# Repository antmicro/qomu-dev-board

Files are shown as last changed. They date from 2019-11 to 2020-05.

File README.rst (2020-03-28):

======================
Qomu Development Board
======================

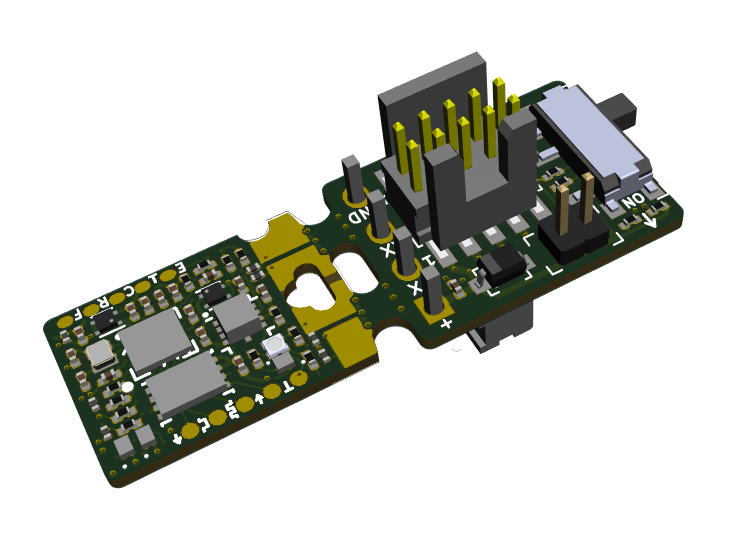
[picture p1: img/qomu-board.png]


Overview
========

This repository contains open hardware design files for the Qomu development board based on the QuickLogic `EOS S3 Sensor Processing Platform <https://www.quicklogic.com/products/eos-s3/>`_.
The design files were created by `Antmicro <https://www.antmicro.com>`_ in cooperation with `QuickLogic <https://www.quicklogic.com/>`_.
The board is small enough to fit into a USB socket.
This allows the user to explore functionalities of the EOS S3 platform on the go without cables or taking up space on your desk.
The board has an additional break-away part with debug connectors that speeds up initial bringup and software development.

Key features
============

* EOS S3 Sensor Processing Platform
* 16Mbit of external flash memory
* Accelerometer
* User RGB LED
* Capacitive touch pads
* Powered with 5.0VDC from USB port
* USB data signals tied to programmable logic

Layout and dimensions
=====================

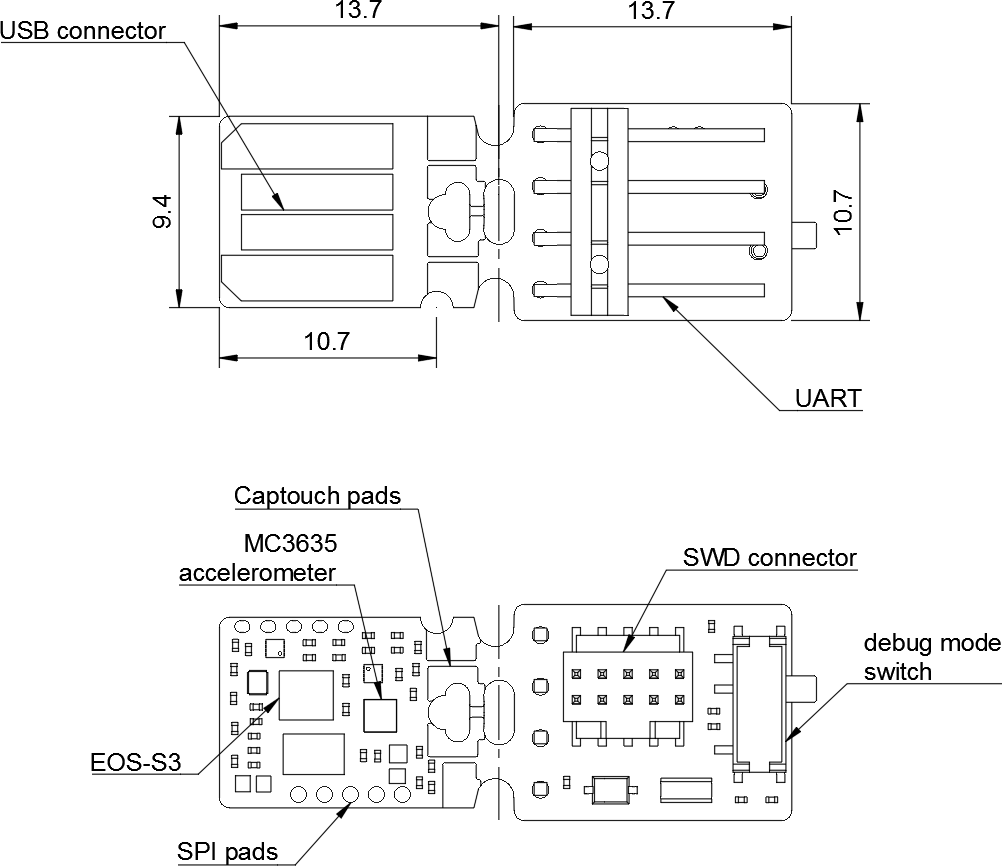
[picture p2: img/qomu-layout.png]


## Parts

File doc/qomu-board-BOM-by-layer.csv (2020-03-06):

Reference | Quantity | Value | Footprint | Manufacturer | MPN | Layer
J2 | 1 | 825437-4 | TE_825437-4 | TE Connectivity | 825437-4 | Top
C1 C15 C16 C2 C7 C9 | 6 | C_2u2_0201 | C_0201_0603Metric | Samsung | CL03A225MP3CRNC | Bottom
C10 C12 C3 C4 C5 C6 C8 | 7 | C_100n_0201 | C_0201_0603Metric | Murata | GRM033R60J104KE19D | Bottom
C13 C14 | 2 | C_8p_0201 | C_0201_0603Metric | Murata | GRM0335C1E8R0DA01D | Bottom
D1 D2 D3 D4 D5 D6 D7 | 7 | D_Small-Device | X1-DFN1006-2 | Diodes Inc. | D5V0L1B2LP3-7 | Bottom
D8 | 1 | SD05C.TCT | SOD-323-SD05 | Semtec | SD05C.TCT | Bottom
IC1 | 1 | EOS-S3 | 42-WLCSP | Quicklogic | EOS-S3-42-WLCSP | Bottom
J1 | 1 | FTSH-105-01-L-DV-K | PinHeader_2x5_P1.27_SMD | Samtec Inc. | FTSH-105-01-L-DV-K | Bottom
J3 | 1 | MC-HVT1-S02-G | PinHeader_1x2_P1.27mm_Drill.7mm_with_622002115121_plug | Multicomp | MC-HVT1-S02-G | Bottom
Q1 Q2 Q3 | 3 | RV1C002UN | VML0806 | ROHM Semiconductor | RV1C002UN | Bottom
R1 R13 R15 R2 R3 R4 R5 R6 | 8 | R_10k_0201 | R_0201_0603Metric | Panasonic | ERJ1GNF1002C | Bottom
R10 R7 | 2 | R_0R_0201 | R_0201_0603Metric | Multicomp | MCRE000086 | Bottom
R11 R12 | 2 | R_22R_0201 | R_0201_0603Metric | Multicomp | MCRE000100 | Bottom
R16 R17 | 2 | R_100R_0201 | R_0201_0603Metric | Multicomp | MCRE000116 | Bottom
R18 | 1 | R_220R_0201 | R_0201_0603Metric | Multicomp | MCRE000124 | Bottom
R8 | 1 | R_4k7_0201 | R_0201_0603Metric | Vishay | CRCW02014K70FNED | Bottom
R9 | 1 | R_1k5_0201 | R_0201_0603Metric | Multicomp | MCRE000144 | Bottom
S1 | 1 | MSS3-V-T_R | Switch_Slide_MSS3 | Diptronics | MSS3-V-T/R | Bottom
U1 U2 | 2 | LDO-X2SON | Texas_X2SON-4_1x1mm_P0.65mm | Microchip | MIC5504-3.3YMT | Bottom
U10 | 1 | RGB-LED | LED-RGB-5DS-UHD1110-FKA | Cree | UHD1110-FKA | Bottom
U4 | 1 | GD25Q16CEIGR | GD25Q16CEIGR | GigaDevice Semiconductor | GD25Q16CEIGR | Bottom
U5 | 1 | MC3635 | MC3635 | mCube | MC3635 | Bottom
XTAL1 | 1 | ECS-_327-12_5-1210-TR | XTAL_ECS-.327-12.5-1210-TR | ECS Inc. | ECS-.327-12.5-1210-TR | Bottom
N1 | 1 | oshw_logo | OSHW-Logo2_7.3x6mm_Copper_Mask |  |  | Virtual
N2 | 1 | antmicro_logo | antmicro-logo_midlayer_4mm |  |  | Virtual
N3 | 1 | ql_logo | Ql_logo_mid_9mm |  |  | Virtual
SW2 | 1 | PADS |  | N/A | N/A | Virtual
TP1 TP10 TP2 TP3 TP4 TP5 TP6 TP7 TP8 TP9 | 10 | TP_SMD_0_75MM | Testpoint_smd_0_75mm |  |  | Virtual
U9 | 1 | USB-B |  | N/A | N/A | Virtual

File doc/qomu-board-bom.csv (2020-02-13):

Reference | Quantity | Value | Footprint | Manufacturer | MPN
C1 C2 C7 C9 | 4 | C_2u2_0201 | C_0201_0603Metric | Samsung | CL03A225MP3CRNC
C10 C11 C12 C3 C4 C5 C6 C8 | 8 | C_100n_0201 | C_0201_0603Metric | Murata | GRM033R60J104KE19D
C13 C14 | 2 | C_8p_0201 | C_0201_0603Metric | Murata | GRM0335C1E8R0DA01D
D1 D2 D3 D4 D5 D6 D7 | 7 | D_Small-Device | X1-DFN1006-2 | Diodes Inc. | D5V0L1B2LP3-7
D8 | 1 | SD05C.TCT | SOD-323-SD05 | Semtec | SD05C.TCT
IC1 | 1 | EOS-S3 | 42-WLCSP | Quicklogic | EOS-S3-42-WLCSP
J1 | 1 | FTSH-105-01-L-DV-K | PinHeader_2x5_P1.27_SMD | Samtec Inc. | FTSH-105-01-L-DV-K
J2 | 1 | 825437-4 | TE_825437-4 | TE Connectivity | 825437-4
J3 | 1 | MC-HVT1-S02-G | PinHeader_1x2_P1.27mm_Drill.7mm_with_622002115121_plug | Multicomp | MC-HVT1-S02-G
N1 | 1 | oshw_logo | OSHW-Logo2_7.3x6mm_Copper_Mask
N2 | 1 | antmicro_logo | antmicro-logo_midlayer_4mm
N3 | 1 | ql_logo | Ql_logo_mid_9mm
Q1 Q2 Q3 | 3 | RV1C002UN | VML0806 | ROHM Semiconductor | RV1C002UN
R1 R13 R15 R2 R3 R4 R5 R6 | 8 | R_10k_0201 | R_0201_0603Metric | Panasonic | ERJ1GNF1002C
R10 R7 | 2 | R_0R_0201 | R_0201_0603Metric | Multicomp | MCRE000086
R11 R12 | 2 | R_22R_0201 | R_0201_0603Metric | MCRE000100
R16 R17 | 2 | R_100R_0201 | R_0201_0603Metric | Multicomp | MCRE000116
R18 | 1 | R_220R_0201 | R_0201_0603Metric | Multicomp | MCRE000124
R8 | 1 | R_4k7_0201 | R_0201_0603Metric | Vishay | CRCW02014K70FNED
R9 | 1 | R_1k5_0201 | R_0201_0603Metric | Multicomp | MCRE000144
S1 | 1 | MSS3-V-T_R | Switch_Slide_MSS3 | Diptronics | MSS3-V-T/R
SW2 | 1 | PADS |  | N/A | N/A
TP1 TP10 TP2 TP3 TP4 TP5 TP6 TP7 TP8 TP9 | 10 | TP_SMD_0_75MM | Testpoint_smd_0_75mm
U1 U2 | 2 | LDO-X2SON | Texas_X2SON-4_1x1mm_P0.65mm | Microchip | MIC5504-3.3YMT
U10 | 1 | RGB-LED | LED-RGB-5DS-UHD1110-FKA | Cree | UHD1110-FKA
U4 | 1 | GD25Q16CEIGR | GD25Q16CEIGR | GigaDevice Semiconductor | GD25Q16CEIGR
U5 | 1 | MC3635 | MC3635 | mCube | MC3635
U9 | 1 | USB-B |  | N/A | N/A
XTAL1 | 1 | ECS-_327-12_5-1210-TR | XTAL_ECS-.327-12.5-1210-TR | ECS Inc. | ECS-.327-12.5-1210-TR

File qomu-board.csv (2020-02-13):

Reference | Value | Footprint | Datasheet | MPN | Manufacturer | Field4 | Field5 | Field6 | Field7 | Field8
U9 | USB-B | qomu-board:USB-PCB |  | N/A | N/A
U10 | UHD1110-FKA | qomu-board-footprints:LED-RGB-5DS-UHD1110-FKA | https://www.cree.com/led-components/media/documents/ds-UHD1110-FKA.pdf | UHD1110-FKA | Cree
R12 | 22R | qomu-board-footprints:R_0201_0603Metric | Multicomp | ANY | MCRE000100
R9 | 1k5 | qomu-board-footprints:R_0201_0603Metric |  | MCRE000144 | Multicomp
SW2 | Captouch Pads | qomu-board:captouch-edge |  | N/A | N/A
D1 | D5V0L1B2LP3-7 | qomu-board-footprints:X1-DFN1006-2 | https://www.diodes.com/assets/Datasheets/D5V0L1B2LP3.pdf | D5V0L1B2LP3-7 | Diodes Inc.
D2 | D5V0L1B2LP3-7 | qomu-board-footprints:X1-DFN1006-2 | https://www.diodes.com/assets/Datasheets/D5V0L1B2LP3.pdf | D5V0L1B2LP3-7 | Diodes Inc.
D3 | D5V0L1B2LP3-7 | qomu-board-footprints:X1-DFN1006-2 | https://www.diodes.com/assets/Datasheets/D5V0L1B2LP3.pdf | D5V0L1B2LP3-7 | Diodes Inc.
D4 | D5V0L1B2LP3-7 | qomu-board-footprints:X1-DFN1006-2 | https://www.diodes.com/assets/Datasheets/D5V0L1B2LP3.pdf | D5V0L1B2LP3-7 | Diodes Inc.
D6 | D5V0L1B2LP3-7 | qomu-board-footprints:X1-DFN1006-2 | https://www.diodes.com/assets/Datasheets/D5V0L1B2LP3.pdf | D5V0L1B2LP3-7 | Diodes Inc.
D7 | D5V0L1B2LP3-7 | qomu-board-footprints:X1-DFN1006-2 | https://www.diodes.com/assets/Datasheets/D5V0L1B2LP3.pdf | D5V0L1B2LP3-7 | Diodes Inc.
D5 | VCUT05E1-SD0 | qomu-board-footprints:X1-DFN1006-2 | http://www.vishay.com/docs/85900/vcut05e1-sd0.pdf | D5V0L1B2LP3-7 | Diodes Inc.
R1 | 10k | qomu-board-footprints:R_0201_0603Metric |  | ERJ1GNF1002C | Panasonic
R11 | 22R | qomu-board-footprints:R_0201_0603Metric | Multicomp | ANY | MCRE000100
C2 | 2u2/10V | qomu-board-footprints:C_0201_0603Metric |  | CL03A225MP3CRNC | Samsung
C9 | 2u2/10V | qomu-board-footprints:C_0201_0603Metric |  | CL03A225MP3CRNC | Samsung
U4 | GD25Q16CEIGR | qomu-board:GD25Q16CEIGR | http://www.gigadevice.com/datasheet/gd25q16c/ | GD25Q16CEIGR | GigaDevice Semiconductor
R3 | 4k7 | qomu-board-footprints:R_0201_0603Metric |  | ERJ1GNF1002C | Panasonic
R4 | 4k7 | qomu-board-footprints:R_0201_0603Metric |  | ERJ1GNF1002C | Panasonic
C5 | 100n | qomu-board-footprints:C_0201_0603Metric |  | GRM033R60J104KE19D | Murata
U5 | MC3635 | qomu-board:MC3635 | https://mcubemems.com/wp-content/uploads/2019/06/MC3635-Datasheet-APS-048-0044v1.6.pdf | MC3635 | mCube
C4 | 100n | qomu-board-footprints:C_0201_0603Metric |  | GRM033R60J104KE19D | Murata
U2 | MIC5504-3.3YMT | qomu-board-footprints:Texas_X2SON-4_1x1mm_P0.65mm |  | MIC5504-3.3YMT | Microchip
C3 | 100n | qomu-board-footprints:C_0201_0603Metric |  | GRM033R60J104KE19D | Murata
C6 | 100n | qomu-board-footprints:C_0201_0603Metric |  | GRM033R60J104KE19D | Murata
C8 | 100n | qomu-board-footprints:C_0201_0603Metric |  | GRM033R60J104KE19D | Murata
C10 | 100n | qomu-board-footprints:C_0201_0603Metric |  | GRM033R60J104KE19D | Murata
C11 | 100n | qomu-board-footprints:C_0201_0603Metric |  | GRM033R60J104KE19D | Murata
U1 | MIC5504-3.3YMT | qomu-board-footprints:Texas_X2SON-4_1x1mm_P0.65mm |  | MIC5504-3.3YMT | Microchip
C7 | 2u2/10V | qomu-board-footprints:C_0201_0603Metric |  | CL03A225MP3CRNC | Samsung
C1 | 2u2/10V | qomu-board-footprints:C_0201_0603Metric |  | CL03A225MP3CRNC | Samsung
R5 | 10k | qomu-board-footprints:R_0201_0603Metric |  | ERJ1GNF1002C | Panasonic
R2 | 10k | qomu-board-footprints:R_0201_0603Metric |  | ERJ1GNF1002C | Panasonic
R8 | 4k7 | qomu-board-footprints:R_0201_0603Metric |  | CRCW02014K70FNED | Vishay
D8 | SD05C.TCT | qomu-board-footprints:SOD-323 | https://www.mouser.com/datasheet/2/761/sdxxc-1277747.pdf | SD05C.TCT | Semtec
J2 | 825437-4 | qomu-board-footprints:TE_825437-4 | https://www.te.com/usa-en/product-825437-4.datasheet.pdf | 825437-4 | TE Connectivity
J1 | FTSH-105-01-L-DV-K | qomu-board-footprints:PinHeader_2x5_P1.27_SMD | http://suddendocs.samtec.com/prints/ftsh-1xx-xx-xxx-dv-xxx-xxx-mkt.pdf | FTSH-105-01-L-DV-K | Samtec Inc.
R15 | 10k | qomu-board-footprints:R_0201_0603Metric |  | ERJ1GNF1002C | Panasonic
R13 | 10k | qomu-board-footprints:R_0201_0603Metric |  | ERJ1GNF1002C | Panasonic
C12 | 100n | qomu-board-footprints:C_0201_0603Metric |  | GRM033R60J104KE19D | Murata
R16 | 100R | qomu-board-footprints:R_0201_0603Metric |  | MCRE000116 | Multicomp
R17 | 100R | qomu-board-footprints:R_0201_0603Metric |  | MCRE000116 | Multicomp
R18 | 220R | qomu-board-footprints:R_0201_0603Metric |  | MCRE000124 | Multicomp
Q2 | RV1C002UN | qomu-board-footprints:VML0806 | https://d1d2qsbl8m0m72.cloudfront.net/en/products/databook/datasheet/discrete/transistor/mosfet/rv1c002un-e.pdf | RV1C002UN | ROHM Semiconductor | RV1C002UN | Nch 20V 180mA Small Signal MOSFET | None | Unavailable | Rohm
Q3 | RV1C002UN | qomu-board-footprints:VML0806 | https://d1d2qsbl8m0m72.cloudfront.net/en/products/databook/datasheet/discrete/transistor/mosfet/rv1c002un-e.pdf | RV1C002UN | ROHM Semiconductor | RV1C002UN | Nch 20V 180mA Small Signal MOSFET | None | Unavailable | Rohm
Q1 | RV1C002UN | qomu-board-footprints:VML0806 | https://d1d2qsbl8m0m72.cloudfront.net/en/products/databook/datasheet/discrete/transistor/mosfet/rv1c002un-e.pdf | RV1C002UN | ROHM Semiconductor | RV1C002UN | Nch 20V 180mA Small Signal MOSFET | None | Unavailable | Rohm
J3 | 22-23-2021 | qomu-board-footprints:PinHeader_1x2_P2.54mm_Drill1.02mm | https://media.digikey.com/pdf/Data%20Sheets/Molex%20PDFs/A-6373-N_Series_Dwg_2010-12-03.pdf | 22-23-2021 | Molex
R6 | 10k | qomu-board-footprints:R_0201_0603Metric |  | ERJ1GNF1002C | Panasonic
C14 | 8p | qomu-board-footprints:C_0201_0603Metric |  | GRM0335C1E8R0DA01D | Murata
C13 | 8p | qomu-board-footprints:C_0201_0603Metric |  | GRM0335C1E8R0DA01D | Murata
XTAL1 | ECS-_327-12_5-1210-TR | qomu-board-footprints:XTAL_ECS-.327-12.5-1210-TR | https://ecsxtal.com/store/pdf/ECX-1210.pdf | ECS-.327-12.5-1210-TR | ECS Inc.
TP2 | TP_SMD_0_75MM | qomu-board-footprints:Testpoint_smd_0_75_0_6mm
IC1 | EOS-S3 | qomu-board:42-WLCSP | https://www.quicklogic.com/wp-content/uploads/2020/06/QL-EOS-S3-Ultra-Low-Power-multicore-MCU-Datasheet.pdf
TP3 | TP_SMD_0_75MM | qomu-board-footprints:Testpoint_smd_0_75_0_6mm
TP5 | TP_SMD_0_75MM | qomu-board-footprints:Testpoint_smd_0_75mm
TP4 | TP_SMD_0_75MM | qomu-board-footprints:Testpoint_smd_0_75mm
TP6 | TP_SMD_0_75MM | qomu-board-footprints:Testpoint_smd_0_75mm
TP7 | TP_SMD_0_75MM | qomu-board-footprints:Testpoint_smd_0_75mm
TP1 | TP_SMD_0_75MM | qomu-board-footprints:Testpoint_smd_0_75_0_6mm
TP8 | TP_SMD_0_75MM | qomu-board-footprints:Testpoint_smd_0_75mm
TP9 | TP_SMD_0_75MM | qomu-board-footprints:Testpoint_smd_0_75_0_6mm

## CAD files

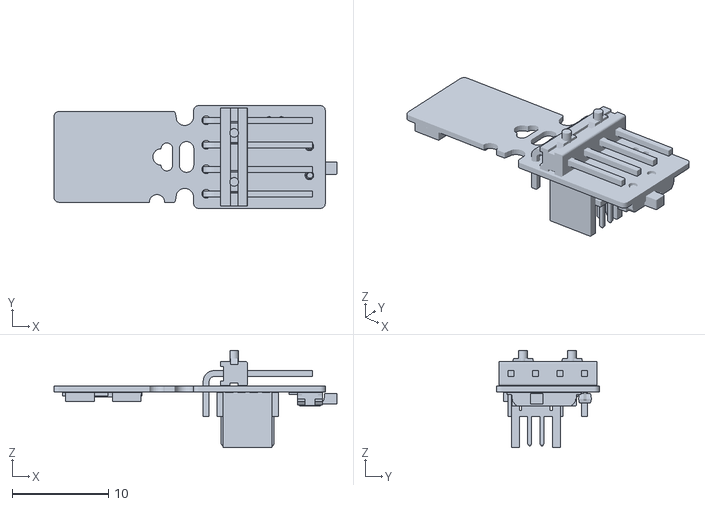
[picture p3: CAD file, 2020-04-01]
3d-model/qomu-model.stl
29.3 x 10.6 x 10.1

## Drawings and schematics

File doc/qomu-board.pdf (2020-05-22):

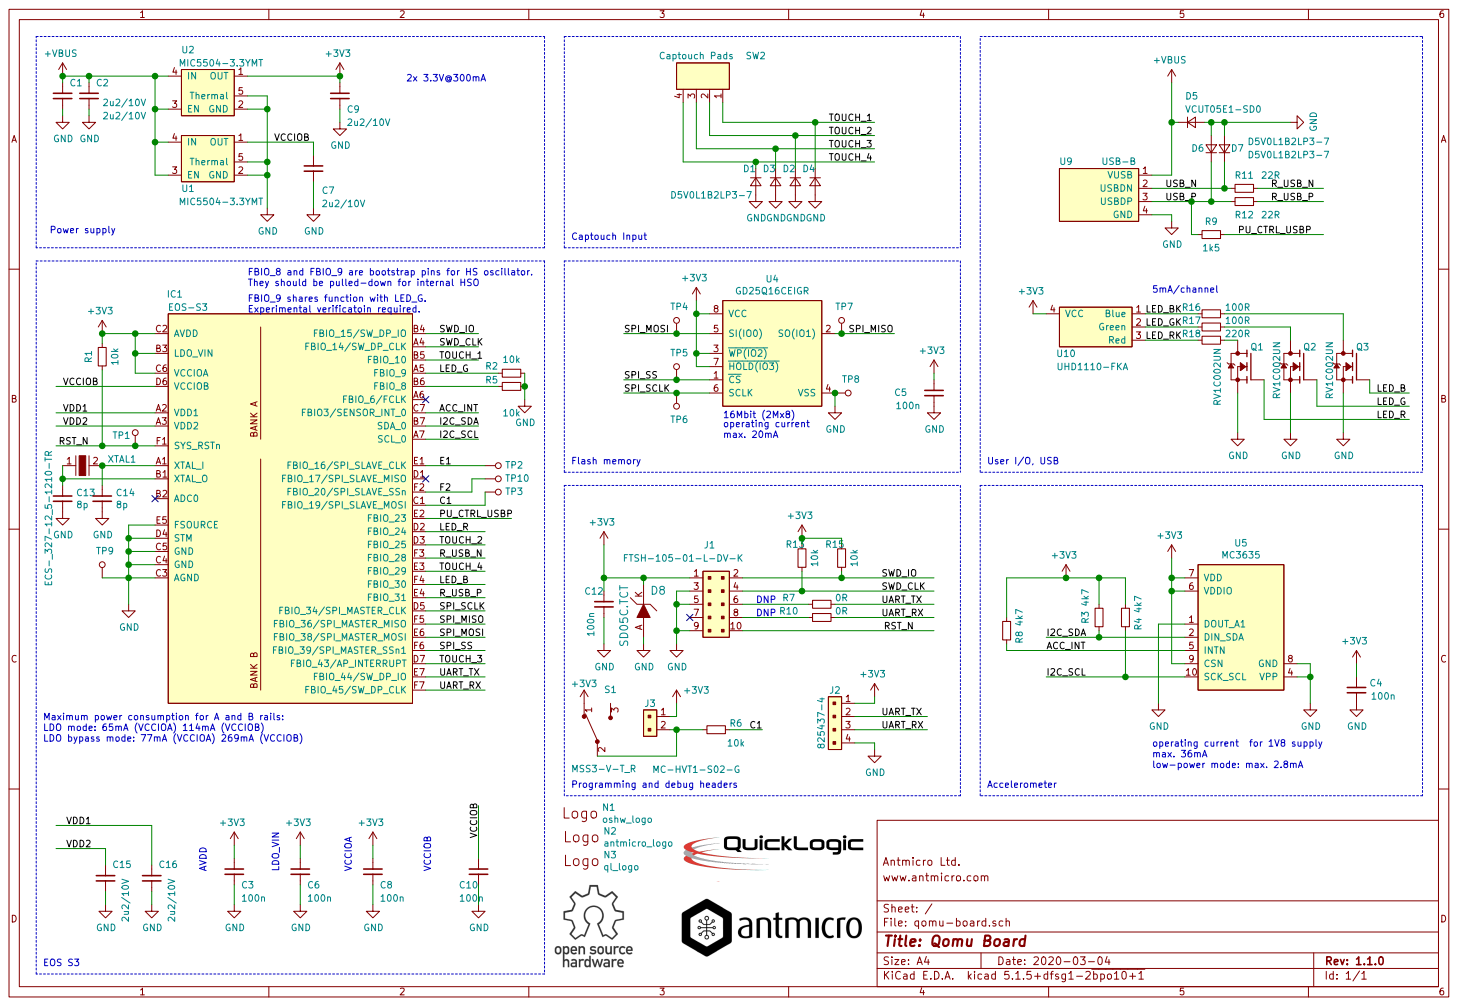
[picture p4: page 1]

FBIO_8 and FBIO_9 are bootstrap pins for HS oscillator.
They should be pulled-down for internal HSO
FBIO_9 shares function with LED_G. Experimental verificatoin required.

5mA/channel Programming and debug headers

VDD2 VDD1
operating current max. 20mA Maximum power consumption for A and B rails:
oshw_logo RST_N

LDO mode: 65mA (VCCIOA) 114mA (VCCIOB)

Antmicro Ltd.
File: qomu-board.sch Sheet: / www.antmicro.com

Id: 1/1 Title: Qomu Board

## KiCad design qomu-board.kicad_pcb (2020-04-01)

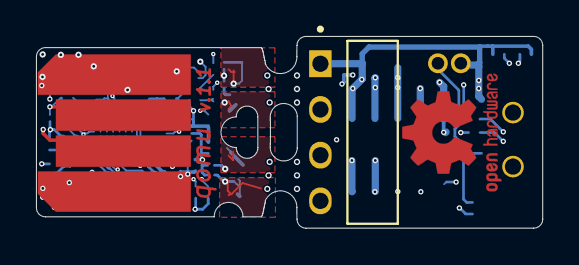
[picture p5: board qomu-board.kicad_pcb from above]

Board: 6 copper layers, 28.1 x 10.6 mm, 69 parts (0 on the bottom side), 45 nets.

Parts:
C1, C2, C7, C9, C15, C16: 2u2/10V; C_0201_0603Metric
C3, C4, C5, C6, C8, C10, C12: 100n; C_0201_0603Metric
C13, C14: 8p; C_0201_0603Metric
D1, D2, D3, D4, D6, D7: D5V0L1B2LP3-7; X1-DFN1006-2
D5: VCUT05E1-SD0; X1-DFN1006-2
D8: SD05C.TCT; SOD-323-SD05
IC1: EOS-S3; 42-WLCSP
J1: FTSH-105-01-L-DV-K; PinHeader_2x5_P1.27_SMD
J2: 825437-4; TE_825437-4
J3: MC-HVT1-S02-G; PinHeader_1x2_P1.27mm_Drill.7mm_with_622002115121_plug
N1: oshw_logo; OSHW-Logo2_7.3x6mm_Copper_Mask
N2: antmicro_logo; antmicro-logo_midlayer_4mm
N3: ql_logo; Ql_logo_mid_9mm
Q1, Q2, Q3: RV1C002UN; VML0806
R1, R2, R5, R6, R13, R15: 10k; R_0201_0603Metric
R3, R4, R8: 4k7; R_0201_0603Metric
R7, R10: 0R; R_0201_0603Metric
R9: 1k5; R_0201_0603Metric
R11, R12: 22R; R_0201_0603Metric
R16, R17: 100R; R_0201_0603Metric
R18: 220R; R_0201_0603Metric
S1: MSS3-V-T_R; Switch_Slide_MSS3
SW2: Captouch Pads; captouch-edge
TP1, TP2, TP3, TP9, TP10: TP_SMD_0_75MM; Testpoint_smd_0_75_0_6mm
TP4, TP5, TP6, TP7, TP8: TP_SMD_0_75MM; Testpoint_smd_0_75mm
U1, U2: MIC5504-3.3YMT; Texas_X2SON-4_1x1mm_P0.65mm
U4: GD25Q16CEIGR
U5: MC3635
U9: USB-B; USB-PCB
U10: UHD1110-FKA; LED-RGB-5DS-UHD1110-FKA
XTAL1: ECS-_327-12_5-1210-TR; XTAL_ECS-.327-12.5-1210-TR

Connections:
+3V3: C3.1, C4.2, C5.2, C6.1, C8.1, C9.1, C12.1, D8.K, IC1.B3, IC1.C2, IC1.C6, J1.1, J2.1, J3.1, R1.2, R3.2, R4.2, R8.2, R13.2, R15.2, S1.1, U2.1, U4.3, U4.7, U4.8, U5.6, U5.7, U5.9, U10.4
+VBUS: C1.1, C2.1, D5.1, U1.3, U1.4, U2.3, U2.4, U9.1
/ACC_INT: IC1.C7, R8.1, U5.5
/C1: IC1.C1, R6.1, TP3.1
/E1: IC1.E1, TP2.1
/F2: IC1.F2, TP10.1
/I2C_SCL: IC1.A7, R4.1, U5.10
/I2C_SDA: IC1.B7, R3.1, U5.2
/LED_B: IC1.F4, Q3.1
/LED_BK: R16.2, U10.1
/LED_G: IC1.A5, Q2.1, R2.1
/LED_GK: R17.2, U10.2
/LED_R: IC1.D2, Q1.1
/LED_RK: R18.2, U10.3
/PU_CTRL_USBP: IC1.E2, R9.1
/RST_N: IC1.F1, J1.10, R1.1, TP1.1
/R_USB_N: IC1.F3, R11.1
/R_USB_P: IC1.E4, R12.1
/SPI_MISO: IC1.F5, TP7.1, U4.2
/SPI_MOSI: IC1.E6, TP4.1, U4.5
/SPI_SCLK: IC1.D5, TP6.1, U4.6
/SPI_SS: IC1.F6, TP5.1, U4.1
/SWD_CLK: IC1.A4, J1.4, R13.1
/SWD_IO: IC1.B4, J1.2, R15.1
/TOUCH_1: D4.1, IC1.B5, SW2.1
/TOUCH_2: D2.1, IC1.D3, SW2.2
/TOUCH_3: D3.1, IC1.D7, SW2.3
/TOUCH_4: D1.1, IC1.E3, SW2.4
/UART_RX: IC1.F7, J2.3, R10.1
/UART_TX: IC1.E7, J2.2, R7.1
/USB_N: D7.1, R11.2, U9.2
/USB_P: D6.1, R9.2, R12.2, U9.3
/VCCIOB: C7.2, C10.1, IC1.D6, U1.1
/VDD1: C16.2, IC1.A2
/VDD2: C15.2, IC1.A3
GND: C1.2, C2.2, C3.2, C4.1, C5.1, C6.2, C7.1, C8.2, C9.2, C10.2, C12.2, C13.2, C14.2, C15.1, C16.1, D1.2, D2.2, D3.2, D4.2, D5.2, D6.2, D7.2, D8.A, IC1.C3, IC1.C4, IC1.C5, IC1.D4, IC1.E5, J1.3, J1.5, J1.9, J2.4, Q1.2, Q2.2, Q3.2, R2.2, R5.1, TP8.1, TP9.1, U1.2, U1.5, U2.2, U2.5, U4.4, U5.1, U5.4, U5.8, U9.4
unnamed: C13.1, IC1.B1, XTAL1.1
unnamed: C14.1, IC1.A1, XTAL1.2
unnamed: IC1.B6, R5.2
unnamed: J1.6, R7.2
unnamed: J1.8, R10.2
unnamed: J3.2, R6.2, S1.2
unnamed: Q1.3, R18.1
unnamed: Q2.3, R17.1
unnamed: Q3.3, R16.1

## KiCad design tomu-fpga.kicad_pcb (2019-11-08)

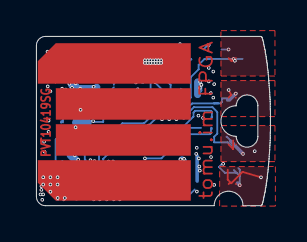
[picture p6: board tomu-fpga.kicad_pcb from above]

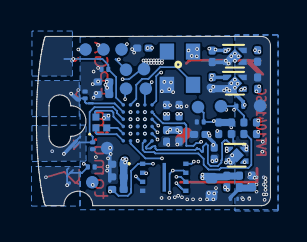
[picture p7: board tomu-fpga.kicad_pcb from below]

Board: 4 copper layers, 13.0 x 9.4 mm, 55 parts (50 on the bottom side), 27 nets.

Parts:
C1, C2, C3, C5, C8, C9, C10, C17, C24, C25: 0201, 1uF, 10V, X5R, 20%; C_0201_0603Metric
C4, C7, C11, C20, C21, C23, C28: 0201, 100nF, 10V, X5R, 20%; C_0201_0603Metric
C22: 0402, 10uF, 6.3V, X5R, 20%; C_0402_1005Metric
D1, D2, D3, D4, D6, D7: D5V0L1B2LP3-7; X1-DFN1006-2
D5: VCUT05E1-SD0; TVS-11V
R1, R5: 0201, 10k, 1/16W; R_0201_0603Metric
R9: 0201, 1.5k, 1/16W, 1%; R_0201_0603Metric
R10: 0201, 100ohm, 1/16W, 1%; R_0201_0603Metric
R11, R12: 0201, 22ohm, 1/16W, 1%; R_0201_0603Metric
SW2: Captouch Pads; captouch-edge
TP1, TP2, TP3, TP4, TP5, TP6, TP7, TP8, TP9, TP10, TP11, TP12: Testpoint; testpoint
U1: LDO-X2SON-1.2V; Texas_X2SON-4_1x1mm_P0.65mm
U2: LDO-X2SON-3.3V; Texas_X2SON-4_1x1mm_P0.65mm
U3: LDO-X2SON-2.5V; Texas_X2SON-4_1x1mm_P0.65mm
U4: SPI Flash; SON50P300X200X60-9N
U5: ICE40UP5K-UWG30; iCE40UP5K-UWG30
U7: Crystal Oscillator; XTAL-2520
U9: USB-B; USB-PCB
U10: RGB-LED; LED-RGB-5DS-UHD1110-FKA
XX1: Touchpad Mask Removal; soldermask-removal
XX2: Case; nothing
XX3: ESD Bag; nothing

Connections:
+1V2: C8.1, C17.1, C20.1, R10.1, U1.1, U2.3, U5.C2
+2V5: C10.1, C21.1, C25.1, U3.1, U5.D4
+3V3: C4.1, C5.1, C7.1, C9.1, C11.2, C24.2, C28.2, R1.2, R5.2, U2.1, U3.3, U4.8, U5.A3, U5.C4, U5.D2, U7.4, U10.4
+5V: C1.1, C2.1, C3.1, D5.1, TP1.1, U1.3, U1.4, U2.4, U3.4, U9.1
/CDONE: TP9.1, U5.D3
/CRESET: R1.1, TP8.1, U5.F3
/ICE_USBN: R11.1, U5.A2
/ICE_USBP: R12.1, U5.A1
/LED_B: U5.C5, U10.1
/LED_G: U5.A5, U10.2
/LED_R: U5.B5, U10.3
/OSC_IN: U5.F4, U7.3
/PU_CTRL_USBP: R9.1, U5.A4
/SPI_CLK: TP5.1, U4.6, U5.D1
/SPI_CS: R5.1, TP4.1, U4.1, U5.C1
/SPI_IO2: TP6.1, U4.3, U5.F2
/SPI_IO3: TP7.1, U4.7, U5.B1
/SPI_MISO: TP3.1, U4.2, U5.E1
/SPI_MOSI: TP2.1, U4.5, U5.F1
/TOUCH_1: D1.1, SW2.1, U5.E4
/TOUCH_2: D2.1, SW2.2, U5.D5
/TOUCH_3: D4.1, SW2.3, U5.E5
/TOUCH_4: D3.1, SW2.4, U5.F5
/USB_N: D7.1, R11.2, TP10.1, U9.2
/USB_P: D6.1, R9.2, R12.2, TP11.1, U9.3
/VCCPLL: C22.2, C23.2, R10.2, U5.B2
GND: C1.2, C2.2, C3.2, C4.2, C5.2, C7.2, C8.2, C9.2, C10.2, C11.1, C17.2, C20.2, C21.2, C22.1, C23.1, C24.1, C25.2, C28.1, D1.2, D2.2, D3.2, D4.2, D5.2, D6.2, D7.2, TP12.1, U1.2, U1.5, U2.2, U2.5, U3.2, U3.5, U4.4, U5.B4, U5.E2, U7.2, U9.4

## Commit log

2019-11-08 Initial commit- PCB design files for Fomu (production) taken from https://github.com/im-tomu/fomu-hardware commit 07383f38da9d5a36aa6105ee2a01cb04b6fe3e73
    [_saved_tomu-fpga.sch, tomu-fpga.kicad_pcb, tomu-fpga.sch]
2019-11-25 Updated project name
    [qomu-board.kicad_pcb, qomu-board.sch, tomu-fpga.sch]
2019-11-25 Schematic/PCB cleanup
    [qomu-board.kicad_pcb, qomu-board.sch]
2020-02-13 Added EOS-S3 and flash memory to schematics
    [qomu-board.kicad_pcb, qomu-board.sch]
2020-02-13 Added accelerometer, changed flash memory
    [qomu-board.kicad_pcb, qomu-board.sch]
2020-02-13 Fixed missing library components, fixed MC3635 footprint
    [qomu-board.kicad_pcb, qomu-board.sch]
2020-02-13 Connected U4 and U5 to EOS S3
    [qomu-board.kicad_pcb, qomu-board.sch]
2020-02-13 Added plastic case outline to PCB, defined initial component placement
    [qomu-board.kicad_pcb, qomu-board.sch]
2020-02-13 Added OSHW logotypes
    [qomu-board.sch]
2020-02-13 Updated component placement
    [qomu-board.kicad_pcb]
2020-02-13 Connected missing nets, schematic cleanup
    [qomu-board.kicad_pcb, qomu-board.sch]
2020-02-13 Fixed USB_D_P pull-up connection, tied U5 CS pin to VDDIO, added some remarks on schematics
    [qomu-board.sch]
2020-02-13 Updated naming
    [qomu-board.sch]
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2020-02-13 Added single LDO as power supply, cleanup
    [qomu-board.sch]
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2020-02-13 Updated MPN for LDO
    [qomu-board.sch]
2020-02-13 Minor changes
    [qomu-board.sch]
2020-02-13 Added notes regarding power consumption
    [qomu-board.sch]
2020-02-13 Added additional LDO and bypass capacitors for EOS S3
    [qomu-board.sch]
2020-02-13 Connected VCCIOA and VCCIOB to proper rails, added power port symbols, added pull-up resistor for IMU interrupt, added bootstrap resistors
    [qomu-board.kicad_pcb, qomu-board.sch]
2020-02-13 Moved all library elements to lib directory, migrated all components to this library
    [qomu-board.kicad_pcb, qomu-board.sch]
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2020-02-13 Added TBDs
    [qomu-board.sch]
2020-02-13 Added BOM
    [qomu-board.csv]
2020-02-13 Minor updates to BOM
    [qomu-board.csv, qomu-board.sch]
2020-02-13 Added headers for debug and programming
    [qomu-board.kicad_pcb, qomu-board.sch]
2020-02-13 Added LED driving transistors
    [qomu-board.kicad_pcb, qomu-board.sch]
2020-02-13 Initial component placement
    [qomu-board.kicad_pcb, qomu-board.sch]
2020-02-13 Component layout condensed to fit plastic enclosure
    [qomu-board.kicad_pcb]
2020-02-13 Library cleanup, added MPNs for all components
    [qomu-board.sch]
2020-02-13 Board shape altered: added debug expansion part
    [qomu-board.kicad_pcb]
2020-02-13 BOM updated
    [qomu-board.csv]
2020-02-13 Updated 3D vis
    [qomu-board.kicad_pcb]
2020-02-13 Connected touch signals to IC1
    [qomu-board.sch]
2020-02-13 Removed R6 and R7
    [qomu-board.sch]
2020-02-13 Removed DBG_SS signal
    [qomu-board.sch]
2020-02-13 Updated PDF with schematic, updated BOM
    [qomu-board.csv, qomu-board.sch]
2020-02-13 Small fixes in BOM
    [qomu-board.csv]
2020-02-13 PCB routing
    [qomu-board.kicad_pcb]
2020-02-13 Added oscillator, updated component placement
    [qomu-board.kicad_pcb, qomu-board.sch]
2020-02-13 TOUCHx connection changed
    [qomu-board.sch]
2020-02-13 Added testpoints to PCB
    [qomu-board.kicad_pcb, qomu-board.sch]
2020-02-13 Added GP testpoints, routing
    [qomu-board.kicad_pcb, qomu-board.sch]
2020-02-13 USB connector position fix
    [qomu-board.kicad_pcb]
2020-02-13 Routing of power planes
    [qomu-board.kicad_pcb]
2020-02-13 Edited tech notes on PCB
    [qomu-board.kicad_pcb, qomu-board.sch]
2020-02-13 Removed soldermask from TOUCHx pads
    [qomu-board.kicad_pcb]
2020-02-13 Changed jumper pitch to 1.27mm, added SMD switch
    [qomu-board.sch]
2020-02-13 Routing completed
    [qomu-board.kicad_pcb, qomu-board.sch]
2020-02-13 Resolved DRC errors
    [qomu-board.kicad_pcb]
2020-02-13 Updated 3D models
    [qomu-board.kicad_pcb]
2020-02-13 Added optional jumpers to enable UART TX/RX on unassigned J1 pins
    [qomu-board.kicad_pcb, qomu-board.sch]
2020-02-13 Updated BOM and 3DVis
    [qomu-board.csv]
2020-02-13 Added Gerber files, updated schematic PDF
    [qomu-board-B_Mask.gbr, qomu-board-B_Paste.gbr, qomu-board-B_SilkS.gbr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]
2020-02-13 Updated schematic notes, re-generated PDF
    [qomu-board.sch]
2020-02-13 Touch_2 and LEDG swapped on schematic. USB_P and Touch_4 (FBIO_31) swapped on schematic
    [qomu-board.sch]
2020-02-13 Fixed footprints for J3 and D8
    [qomu-board.sch]
2020-02-13 Pin swaps implemented on PCB
    [qomu-board.kicad_pcb]
2020-02-13 Testpoint on F2 added
    [qomu-board.kicad_pcb, qomu-board.sch]
2020-02-13 R7,R10,S1 options restored. Library link fixed
    [qomu-board.kicad_pcb, qomu-board.sch]
2020-02-13 Added logotypes, updated copper ballance
    [qomu-board.kicad_pcb, qomu-board.sch]
2020-02-13 Updated descriptions on silk overlay
    [qomu-board.kicad_pcb]
2020-02-13 Updated gerber files, updated schematic PDF
    [qomu-board-B_Adhes.gbr, qomu-board-B_CrtYd.gbr, qomu-board-B_Fab.gbr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]
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2020-02-13 Added documentation for manufacturing prototypes in rev. 1.0
    [qomu-board-B_Adhes.gbr, qomu-board-B_CrtYd.gbr, qomu-board-B_Fab.gbr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]
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2020-02-13 PCB adopted to narrower version of GD25Q16, revision changed to 1.1
    [qomu-board.kicad_pcb, qomu-board.sch]
2020-02-13 Added production files for rev. 1.1
    [qomu-board-BOM-populated.csv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]
2020-03-06 Updated pin 1 marking on RGB LED
    [qomu-board.kicad_pcb]
2020-03-06 Added bulk capacitors to EOS internal VDD1/1. Removed C11
    [qomu-board.kicad_pcb, qomu-board.sch]
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2020-03-06 U4 designator is now hidden
    [qomu-board.kicad_pcb]
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2020-04-01 LED_G reconnected to FBIO9
    [qomu-board.kicad_pcb, qomu-board.sch]
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2020-04-01 Add 3D STL model
    [qomu-model.stl]
2020-05-22 Update documentation for release 1.1.0
    [qomu-board-B_Adhes.gbr, qomu-board-B_CrtYd.gbr, qomu-board-B_Fab.gbr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]

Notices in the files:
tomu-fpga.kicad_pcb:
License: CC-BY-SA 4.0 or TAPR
